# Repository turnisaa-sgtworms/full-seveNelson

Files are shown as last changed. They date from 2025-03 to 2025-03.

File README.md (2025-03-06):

my fun little keeb: 



designed to fit in a 60% case (minus two of the mounting points)

7u main cluster with a southy num pad and arrow keys/mini nav cluster

stm32 powered

built with the help of this guide: https://youtu.be/kGKN8SGkUD0?si=LNXGM9T6t6xvs4m5
by noah kiser

plate files are added, but will need updated when i fix the spacing :(

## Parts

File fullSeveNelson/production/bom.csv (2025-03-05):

Designator | Footprint | Quantity | Value | LCSC Part #
 |  | 1
BOOT1, RST1 | SW_SPST_TL3342 | 2 | SW_SPST
C1, C3, C4, C5, C6, C7, C8 | 0402 | 7 | 100nF | C307331
C10, C9 | 0402 | 2 | 1uF | C307331
C2 | 0603 | 1 | 10uF | C307331
D10, D11, D12, D13, D14, D15, D16, D17, D18, D19, D2, D20, D21, D22, D23, D24, D25, D26, D27, D28, D29, D3, D30, D31, D32, D33, D34, D35, D36, D37, D38, D39, D4, D40, D41, D42, D43, D44, D45, D46, D47, D48, D49, D5, D50, D51, D52, D53, D54, D55, D56, D57, D58, D6, D7, D8, D9 | D_SOD-123 | 57 | D_Small
F1 | 1206 | 1 | 500mA | C135341
J1 | USB_C_Receptacle_HRO_TYPE-C-31-M-12 | 1 | USB_C_Receptacle_USB2.0
MX10, MX11, MX12, MX13, MX14, MX15, MX16, MX17, MX18, MX19, MX2, MX20, MX21, MX22, MX23, MX24, MX25, MX26, MX27, MX28, MX29, MX3, MX30, MX31, MX32, MX33, MX34, MX35, MX36, MX37, MX38, MX39, MX4, MX40, MX41, MX42, MX43, MX44, MX45, MX46, MX47, MX48, MX49, MX5, MX50, MX51, MX52, MX53, MX54, MX55, MX56, MX57, MX58, MX6, MX7, MX8, MX9 | SW_MX_HS_CPG151101S11_1u | 57 | MX_SW_HS
R1, R2, R3, R4 | 0402 | 4 | 5.1k
U1 | LQFP-48_7x7mm_P0.5mm | 1 | STM32F072CBT6
U2 | SOT-143 | 1 | PRTR5V0U2X | C2827688
U3 | SOT-23 | 1 | XC6206PxxxMR-Regulator_Linear | C5446

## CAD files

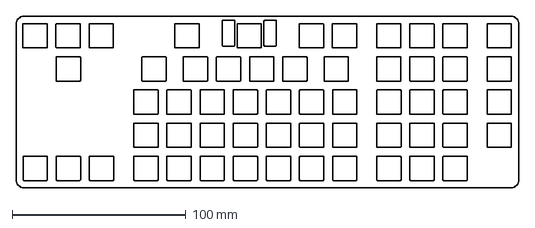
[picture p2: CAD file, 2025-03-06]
plate files/fsnPlate.dxf
289.0 x 98.6 mm

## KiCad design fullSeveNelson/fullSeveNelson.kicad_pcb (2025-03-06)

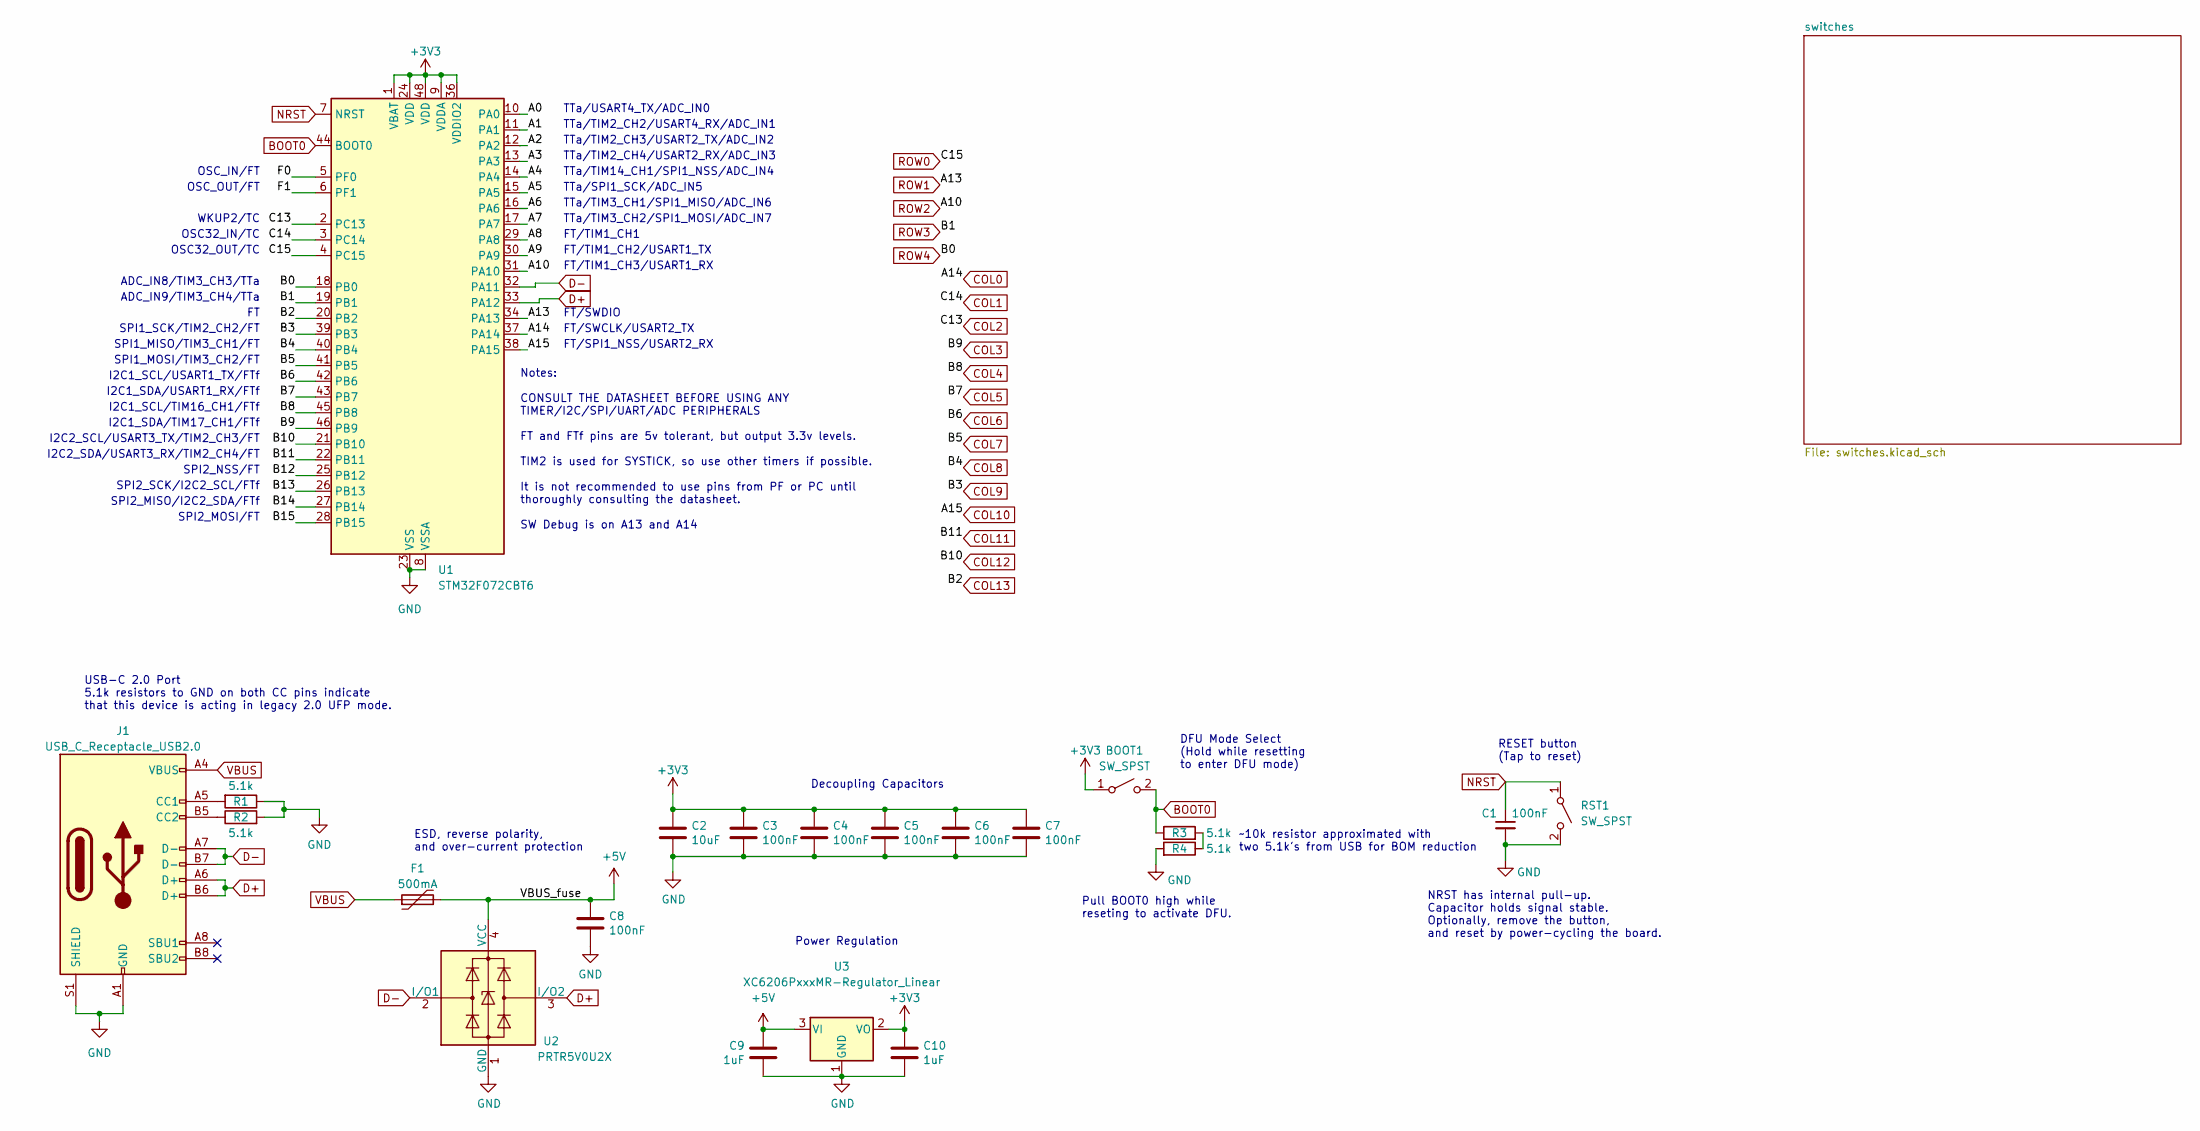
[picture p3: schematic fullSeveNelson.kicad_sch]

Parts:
BOOT1: SW_SPST; SW_SPST_TL3342
C1, C3, C4, C5, C6, C7, C8: 100nF; C_0402_1005Metric; LCSC C307331
C2: 10uF; C_0603_1608Metric; LCSC C307331
C9, C10: 1uF; C_0402_1005Metric; LCSC C307331
F1: 500mA; Fuse_1206_3216Metric; LCSC C135341
J1: USB_C_Receptacle_USB2.0; USB_C_Receptacle_HRO_TYPE-C-31-M-12; JlcRotOffset 180
R1, R2, R3, R4: 5.1k; R_0402_1005Metric
RST1: SW_SPST; SW_SPST_TL3342
U1: STM32F072CBT6; LQFP-48_7x7mm_P0.5mm; JlcRotOffset 90
U2: PRTR5V0U2X; SOT-143; LCSC C2827688
U3: XC6206PxxxMR-Regulator_Linear; SOT-23; LCSC C5446

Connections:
+3V3: BOOT1.1 (A), C2.1, C3.1, C4.1, C5.1, C6.1, C7.1, C10.1, U1.1 (VBAT), U1.9 (VDDA), U1.24 (VDD), U1.36 (VDDIO2), U1.48 (VDD), U3.2 (VO)
+5V: C8.1, C9.1, F1.2, U2.4 (VCC), U3.3 (VI)
/A0: U1.10 (PA0)
/A1: U1.11 (PA1)
/A2: U1.12 (PA2)
/A3: U1.13 (PA3)
/A4: U1.14 (PA4)
/A5: U1.15 (PA5)
/A6: U1.16 (PA6)
/A7: U1.17 (PA7)
/A8: U1.29 (PA8)
/A9: U1.30 (PA9)
/B12: U1.25 (PB12)
/B13: U1.26 (PB13)
/B14: U1.27 (PB14)
/B15: U1.28 (PB15)
/F0: U1.5 (PF0)
/F1: U1.6 (PF1)
BOOT0: BOOT1.2 (B), R3.1, U1.44 (BOOT0)
COL0: U1.37 (PA14); also elsewhere on the board
COL1: U1.3 (PC14); also elsewhere on the board
COL2: U1.2 (PC13); also elsewhere on the board
COL3: U1.46 (PB9); also elsewhere on the board
COL4: U1.45 (PB8); also elsewhere on the board
COL5: U1.43 (PB7); also elsewhere on the board
COL6: U1.42 (PB6); also elsewhere on the board
COL7: U1.41 (PB5); also elsewhere on the board
COL8: U1.40 (PB4); also elsewhere on the board
COL9: U1.39 (PB3); also elsewhere on the board
COL10: U1.38 (PA15); also elsewhere on the board
COL11: U1.22 (PB11); also elsewhere on the board
COL12: U1.21 (PB10); also elsewhere on the board
COL13: U1.20 (PB2); also elsewhere on the board
D+: J1.A6 (D+), J1.B6 (D+), U1.33 (PA12), U2.3 (I/O2)
D-: J1.A7 (D-), J1.B7 (D-), U1.32 (PA11), U2.2 (I/O1)
GND: C1.2, C2.2, C3.2, C4.2, C5.2, C6.2, C7.2, C8.2, C9.2, C10.2, J1.A1 (GND), J1.A12 (GND), J1.B1 (GND), J1.B12 (GND), J1.S1 (SHIELD), R1.1, R2.2, R4.2, RST1.2 (B), U1.8 (VSSA), U1.23 (VSS), U1.35 (VSS), U1.47 (VSS), U2.1 (GND), U3.1 (GND)
NRST: C1.1, RST1.1 (A), U1.7 (NRST)
unnamed: J1.A5 (CC1), R1.2
unnamed: J1.B5 (CC2), R2.1
unnamed: R3.2, R4.1
ROW0: U1.4 (PC15); also elsewhere on the board
ROW1: U1.34 (PA13); also elsewhere on the board
ROW2: U1.31 (PA10); also elsewhere on the board
ROW3: U1.19 (PB1); also elsewhere on the board
ROW4: U1.18 (PB0); also elsewhere on the board
VBUS: F1.1, J1.A4 (VBUS), J1.A9 (VBUS), J1.B4 (VBUS), J1.B9 (VBUS)

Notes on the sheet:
SPI1_SCK/TIM2_CH2/FT
FT/TIM1_CH1
FT/TIM1_CH3/USART1_RX
SPI2_NSS/FT
Notes: CONSULT THE DATASHEET BEFORE USING ANY TIMER/I2C/SPI/UART/ADC PERIPHERALS FT and FTf pins are 5v tolerant, but output 3.3v levels. TIM2 is used for SYSTICK, so use other timers if possible. It is not recommended to use pins from PF or PC until thoroughly consulting the datasheet. SW Debug is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
TTa/TIM2_CH4/USART2_RX/ADC_IN3
NRST has internal pull-up. Capacitor holds signal stable. Optionally, remove the button, and reset by power-cycling the board.
FT/SWDIO
Decoupling Capacitors
SPI1_MOSI/TIM3_CH2/FT
ADC_IN9/TIM3_CH4/TTa
I2C2_SCL/USART3_TX/TIM2_CH3/FT
SPI2_MISO/I2C2_SDA/FTf
FT/SWCLK/USART2_TX
I2C1_SCL/TIM16_CH1/FTf
~10k resistor approximated with two 5.1k's from USB for BOM reduction
TTa/TIM2_CH2/USART4_RX/ADC_IN1
USB-C 2.0 Port 5.1k resistors to GND on both CC pins indicate that this device is acting in legacy 2.0 UFP mode.
TTa/TIM2_CH3/USART2_TX/ADC_IN2
OSC_IN/FT
DFU Mode Select (Hold while resetting to enter DFU mode)
WKUP2/TC
I2C2_SDA/USART3_RX/TIM2_CH4/FT
ADC_IN8/TIM3_CH3/TTa
RESET button (Tap to reset)
Pull BOOT0 high while reseting to activate DFU.
I2C1_SDA/TIM17_CH1/FTf
TTa/SPI1_SCK/ADC_IN5
TTa/TIM3_CH1/SPI1_MISO/ADC_IN6
TTa/TIM3_CH2/SPI1_MOSI/ADC_IN7
OSC32_OUT/TC
FT/SPI1_NSS/USART2_RX
SPI1_MISO/TIM3_CH1/FT
OSC32_IN/TC
TTa/TIM14_CH1/SPI1_NSS/ADC_IN4
I2C1_SDA/USART1_RX/FTf
SPI2_MOSI/FT
FT/TIM1_CH2/USART1_TX
Power Regulation
SPI2_SCK/I2C2_SCL/FTf

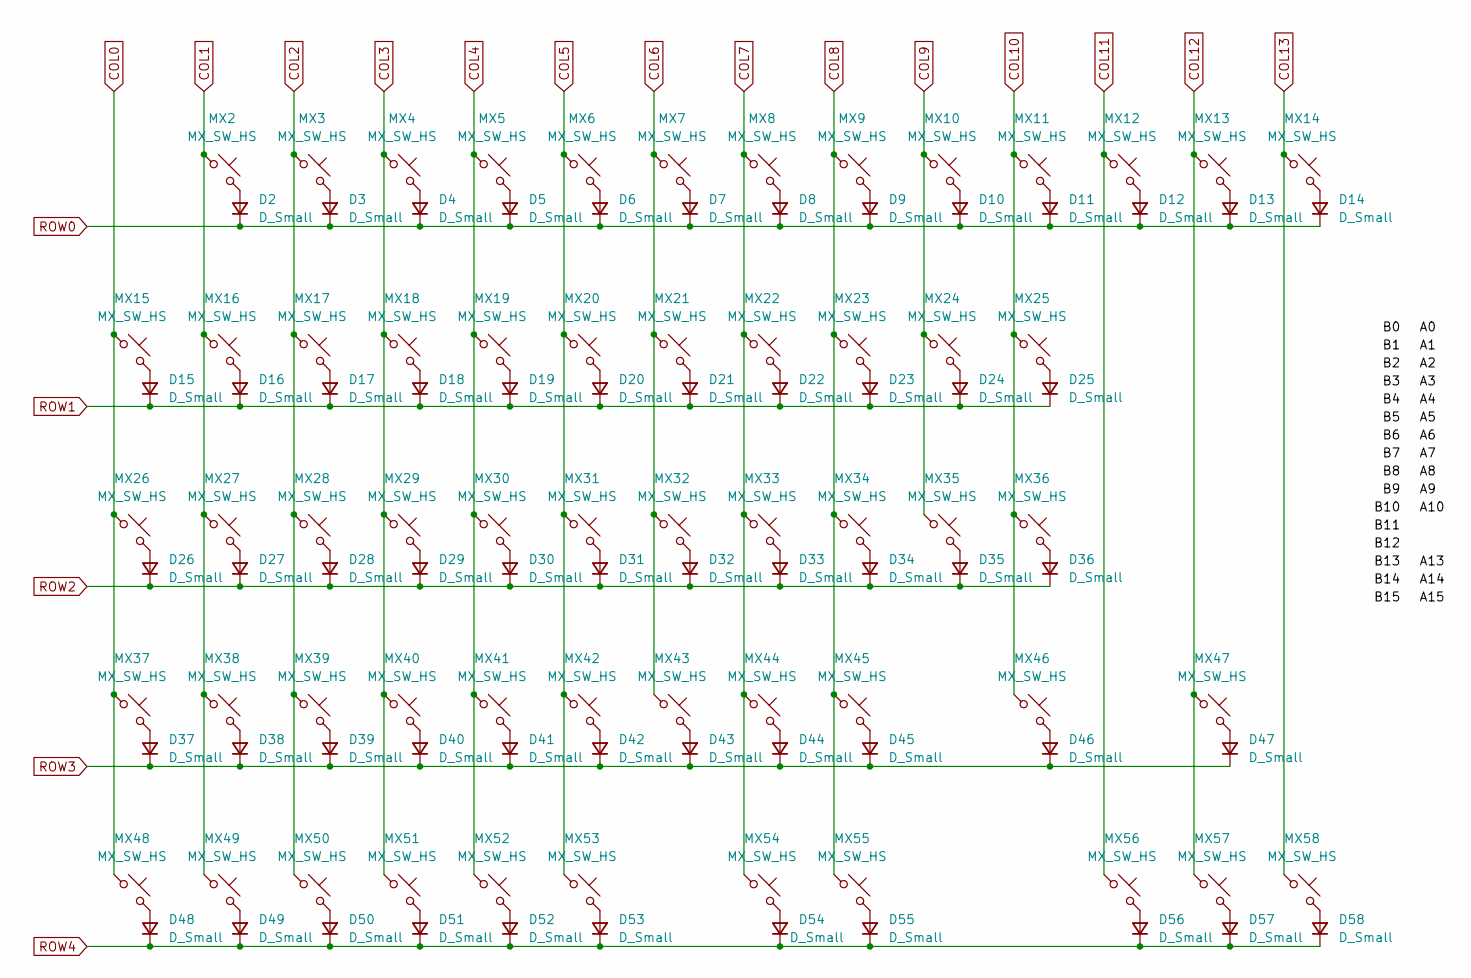
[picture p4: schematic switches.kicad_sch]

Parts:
D2, D3, D4, D5, D6, D7, D8, D9, D10, D11, D12, D13, D14, D15, D16, D17, D18, D19, D20, D21, D22, D23, D24, D25, D26, D27, D28, D29, D30, D31, D32, D33, D34, D35, D36, D37, D38, D39, D40, D41, D42, D43, D44, D45, D46, D47, D48, D49, D50, D51, D52, D53, D54, D55, D56, D57, D58: D_Small; D_SOD-123
MX2, MX3, MX4, MX5, MX6, MX7, MX8, MX9, MX10, MX11, MX12, MX13, MX14, MX15, MX16, MX17, MX18, MX19, MX20, MX21, MX22, MX23, MX24, MX25, MX26, MX27, MX28, MX29, MX30, MX31, MX32, MX33, MX34, MX35, MX36, MX37, MX38, MX39, MX40, MX41, MX42, MX43, MX44, MX45, MX46, MX47, MX48, MX49, MX50, MX51, MX52, MX53, MX54, MX55, MX56, MX57, MX58: MX_SW_HS; SW_MX_HS_CPG151101S11_1u

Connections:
COL0: MX15.1, MX26.1, MX37.1, MX48.1; also elsewhere on the board
COL1: MX2.1, MX16.1, MX27.1, MX38.1, MX49.1; also elsewhere on the board
COL2: MX3.1, MX17.1, MX28.1, MX39.1, MX50.1; also elsewhere on the board
COL3: MX4.1, MX18.1, MX29.1, MX40.1, MX51.1; also elsewhere on the board
COL4: MX5.1, MX19.1, MX30.1, MX41.1, MX52.1; also elsewhere on the board
COL5: MX6.1, MX20.1, MX31.1, MX42.1, MX53.1; also elsewhere on the board
COL6: MX7.1, MX21.1, MX32.1, MX43.1; also elsewhere on the board
COL7: MX8.1, MX22.1, MX33.1, MX44.1, MX54.1; also elsewhere on the board
COL8: MX9.1, MX23.1, MX34.1, MX45.1, MX55.1; also elsewhere on the board
COL9: MX10.1, MX24.1, MX35.1; also elsewhere on the board
COL10: MX11.1, MX25.1, MX36.1, MX46.1; also elsewhere on the board
COL11: MX12.1, MX56.1; also elsewhere on the board
COL12: MX13.1, MX47.1, MX57.1; also elsewhere on the board
COL13: MX14.1, MX58.1; also elsewhere on the board
unnamed: D2.2 (A), MX2.2
unnamed: D3.2 (A), MX3.2
unnamed: D4.2 (A), MX4.2
unnamed: D5.2 (A), MX5.2
unnamed: D6.2 (A), MX6.2
unnamed: D7.2 (A), MX7.2
unnamed: D8.2 (A), MX8.2
unnamed: D9.2 (A), MX9.2
unnamed: D10.2 (A), MX10.2
unnamed: D11.2 (A), MX11.2
unnamed: D12.2 (A), MX12.2
unnamed: D13.2 (A), MX13.2
unnamed: D14.2 (A), MX14.2
unnamed: D15.2 (A), MX15.2
unnamed: D16.2 (A), MX16.2
unnamed: D17.2 (A), MX17.2
unnamed: D18.2 (A), MX18.2
unnamed: D19.2 (A), MX19.2
unnamed: D20.2 (A), MX20.2
unnamed: D21.2 (A), MX21.2
unnamed: D22.2 (A), MX22.2
unnamed: D23.2 (A), MX23.2
unnamed: D24.2 (A), MX24.2
unnamed: D25.2 (A), MX25.2
unnamed: D26.2 (A), MX26.2
unnamed: D27.2 (A), MX27.2
unnamed: D28.2 (A), MX28.2
unnamed: D29.2 (A), MX29.2
unnamed: D30.2 (A), MX30.2
unnamed: D31.2 (A), MX31.2
unnamed: D32.2 (A), MX32.2
unnamed: D33.2 (A), MX33.2
unnamed: D34.2 (A), MX34.2
unnamed: D35.2 (A), MX35.2
unnamed: D36.2 (A), MX36.2
unnamed: D37.2 (A), MX37.2
unnamed: D38.2 (A), MX38.2
unnamed: D39.2 (A), MX39.2
unnamed: D40.2 (A), MX40.2
unnamed: D41.2 (A), MX41.2
unnamed: D42.2 (A), MX42.2
unnamed: D43.2 (A), MX43.2
unnamed: D44.2 (A), MX44.2
unnamed: D45.2 (A), MX45.2
unnamed: D46.2 (A), MX46.2
unnamed: D47.2 (A), MX47.2
unnamed: D48.2 (A), MX48.2
unnamed: D49.2 (A), MX49.2
unnamed: D50.2 (A), MX50.2
unnamed: D51.2 (A), MX51.2
unnamed: D52.2 (A), MX52.2
unnamed: D53.2 (A), MX53.2
unnamed: D54.2 (A), MX54.2
unnamed: D55.2 (A), MX55.2
unnamed: D56.2 (A), MX56.2
unnamed: D57.2 (A), MX57.2
unnamed: D58.2 (A), MX58.2
ROW0: D2.1 (K), D3.1 (K), D4.1 (K), D5.1 (K), D6.1 (K), D7.1 (K), D8.1 (K), D9.1 (K), D10.1 (K), D11.1 (K), D12.1 (K), D13.1 (K), D14.1 (K); also elsewhere on the board
ROW1: D15.1 (K), D16.1 (K), D17.1 (K), D18.1 (K), D19.1 (K), D20.1 (K), D21.1 (K), D22.1 (K), D23.1 (K), D24.1 (K), D25.1 (K); also elsewhere on the board
ROW2: D26.1 (K), D27.1 (K), D28.1 (K), D29.1 (K), D30.1 (K), D31.1 (K), D32.1 (K), D33.1 (K), D34.1 (K), D35.1 (K), D36.1 (K); also elsewhere on the board
ROW3: D37.1 (K), D38.1 (K), D39.1 (K), D40.1 (K), D41.1 (K), D42.1 (K), D43.1 (K), D44.1 (K), D45.1 (K), D46.1 (K), D47.1 (K); also elsewhere on the board
ROW4: D48.1 (K), D49.1 (K), D50.1 (K), D51.1 (K), D52.1 (K), D53.1 (K), D54.1 (K), D55.1 (K), D56.1 (K), D57.1 (K), D58.1 (K); also elsewhere on the board

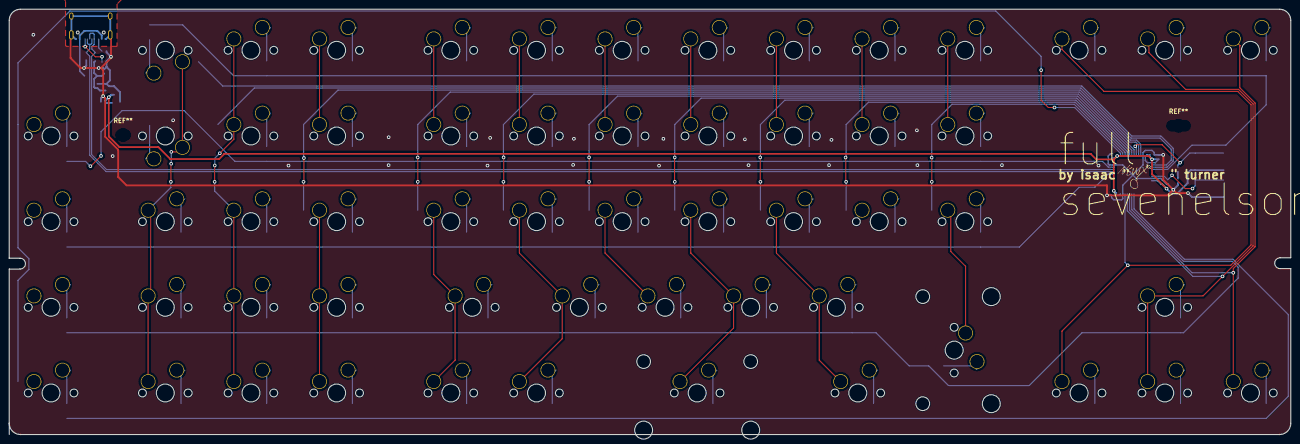
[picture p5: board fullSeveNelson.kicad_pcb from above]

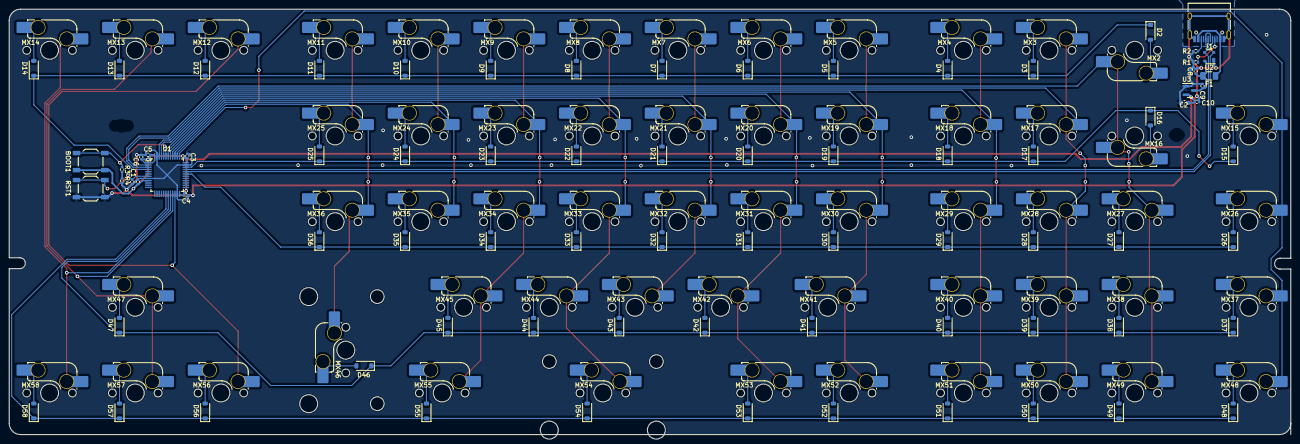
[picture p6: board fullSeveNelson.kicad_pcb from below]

Board: 2 copper layers, 285.0 x 94.6 mm, 135 parts (135 on the bottom side), 87 nets.

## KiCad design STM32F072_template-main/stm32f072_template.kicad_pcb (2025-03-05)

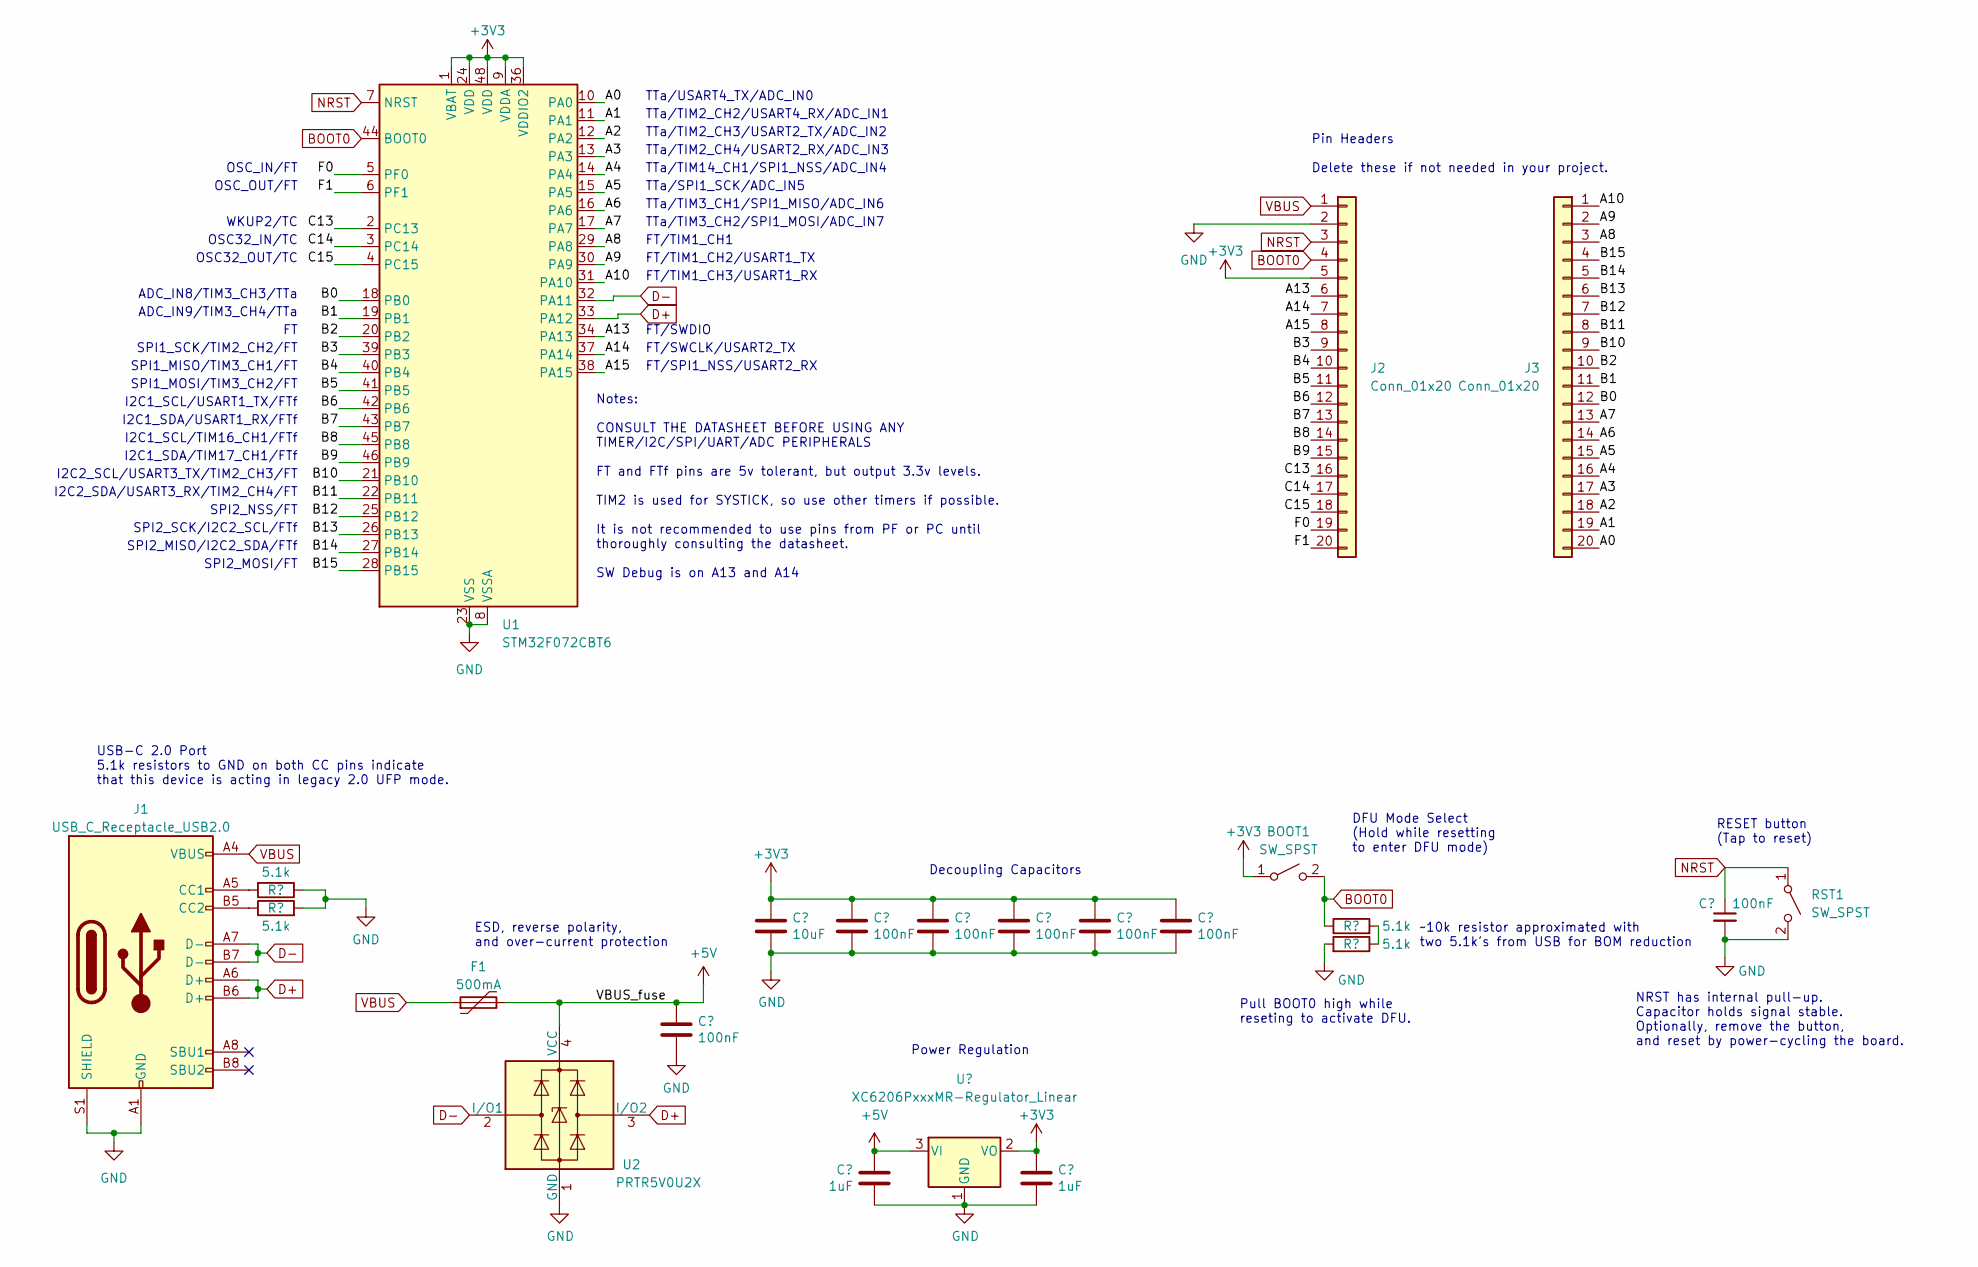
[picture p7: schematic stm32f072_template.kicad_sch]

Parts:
BOOT1: SW_SPST; SW_SPST_TL3342
C1, C3, C4, C5, C6, C7, C8: 100nF; C_0402_1005Metric; LCSC C307331
C2: 10uF; C_0603_1608Metric; LCSC C307331
C9, C10: 1uF; C_0402_1005Metric; LCSC C307331
F1: 500mA; Fuse_1206_3216Metric; LCSC C135341
J1: USB_C_Receptacle_USB2.0; USB_C_Receptacle_HRO_TYPE-C-31-M-12; JlcRotOffset 180
J2, J3: Conn_01x20; PinHeader_1x20_P2.54mm_Vertical
R1, R2, R3, R4: 5.1k; R_0402_1005Metric
RST1: SW_SPST; SW_SPST_TL3342
U1: STM32F072CBT6; LQFP-48_7x7mm_P0.5mm; JlcRotOffset 90
U2: PRTR5V0U2X; SOT-143; LCSC C2827688
U3: XC6206PxxxMR-Regulator_Linear; SOT-23; LCSC C5446

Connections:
+3V3: BOOT1.1 (A), C2.1, C3.1, C4.1, C5.1, C6.1, C7.1, C10.1, J2.5, U1.1 (VBAT), U1.9 (VDDA), U1.24 (VDD), U1.36 (VDDIO2), U1.48 (VDD), U3.2 (VO)
+5V: C8.1, C9.1, F1.2, U2.4 (VCC), U3.3 (VI)
/A0: J3.20, U1.10 (PA0)
/A1: J3.19, U1.11 (PA1)
/A2: J3.18, U1.12 (PA2)
/A3: J3.17, U1.13 (PA3)
/A4: J3.16, U1.14 (PA4)
/A5: J3.15, U1.15 (PA5)
/A6: J3.14, U1.16 (PA6)
/A7: J3.13, U1.17 (PA7)
/A8: J3.3, U1.29 (PA8)
/A9: J3.2, U1.30 (PA9)
/A10: J3.1, U1.31 (PA10)
/A13: J2.6, U1.34 (PA13)
/A14: J2.7, U1.37 (PA14)
/A15: J2.8, U1.38 (PA15)
/B0: J3.12, U1.18 (PB0)
/B1: J3.11, U1.19 (PB1)
/B2: J3.10, U1.20 (PB2)
/B3: J2.9, U1.39 (PB3)
/B4: J2.10, U1.40 (PB4)
/B5: J2.11, U1.41 (PB5)
/B6: J2.12, U1.42 (PB6)
/B7: J2.13, U1.43 (PB7)
/B8: J2.14, U1.45 (PB8)
/B9: J2.15, U1.46 (PB9)
/B10: J3.9, U1.21 (PB10)
/B11: J3.8, U1.22 (PB11)
/B12: J3.7, U1.25 (PB12)
/B13: J3.6, U1.26 (PB13)
/B14: J3.5, U1.27 (PB14)
/B15: J3.4, U1.28 (PB15)
/C13: J2.16, U1.2 (PC13)
/C14: J2.17, U1.3 (PC14)
/C15: J2.18, U1.4 (PC15)
/F0: J2.19, U1.5 (PF0)
/F1: J2.20, U1.6 (PF1)
BOOT0: BOOT1.2 (B), J2.4, R3.1, U1.44 (BOOT0)
GND: C1.2, C2.2, C3.2, C4.2, C5.2, C6.2, C7.2, C8.2, C9.2, C10.2, J1.A1 (GND), J1.A12 (GND), J1.B1 (GND), J1.B12 (GND), J1.S1 (SHIELD), J2.2, R1.1, R2.2, R4.2, RST1.2 (B), U1.8 (VSSA), U1.23 (VSS), U1.35 (VSS), U1.47 (VSS), U2.1 (GND), U3.1 (GND)
NRST: C1.1, J2.3, RST1.1 (A), U1.7 (NRST)
unnamed: J1.A5 (CC1), R1.2
unnamed: J1.B5 (CC2), R2.1
unnamed: R3.2, R4.1
VBUS: F1.1, J1.A4 (VBUS), J1.A9 (VBUS), J1.B4 (VBUS), J1.B9 (VBUS), J2.1

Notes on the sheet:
SPI1_SCK/TIM2_CH2/FT
Pin Headers Delete these if not needed in your project.
FT/TIM1_CH1
FT/TIM1_CH3/USART1_RX
SPI2_NSS/FT
Notes: CONSULT THE DATASHEET BEFORE USING ANY TIMER/I2C/SPI/UART/ADC PERIPHERALS FT and FTf pins are 5v tolerant, but output 3.3v levels. TIM2 is used for SYSTICK, so use other timers if possible. It is not recommended to use pins from PF or PC until thoroughly consulting the datasheet. SW Debug is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
TTa/TIM2_CH4/USART2_RX/ADC_IN3
NRST has internal pull-up. Capacitor holds signal stable. Optionally, remove the button, and reset by power-cycling the board.
FT/SWDIO
Decoupling Capacitors
SPI1_MOSI/TIM3_CH2/FT
ADC_IN9/TIM3_CH4/TTa
I2C2_SCL/USART3_TX/TIM2_CH3/FT
SPI2_MISO/I2C2_SDA/FTf
FT/SWCLK/USART2_TX
I2C1_SCL/TIM16_CH1/FTf
~10k resistor approximated with two 5.1k's from USB for BOM reduction
TTa/TIM2_CH2/USART4_RX/ADC_IN1
USB-C 2.0 Port 5.1k resistors to GND on both CC pins indicate that this device is acting in legacy 2.0 UFP mode.
TTa/TIM2_CH3/USART2_TX/ADC_IN2
OSC_IN/FT
DFU Mode Select (Hold while resetting to enter DFU mode)
WKUP2/TC
I2C2_SDA/USART3_RX/TIM2_CH4/FT
ADC_IN8/TIM3_CH3/TTa
RESET button (Tap to reset)
Pull BOOT0 high while reseting to activate DFU.
I2C1_SDA/TIM17_CH1/FTf
TTa/SPI1_SCK/ADC_IN5
TTa/TIM3_CH1/SPI1_MISO/ADC_IN6
TTa/TIM3_CH2/SPI1_MOSI/ADC_IN7
OSC32_OUT/TC
FT/SPI1_NSS/USART2_RX
SPI1_MISO/TIM3_CH1/FT
OSC32_IN/TC
TTa/TIM14_CH1/SPI1_NSS/ADC_IN4
I2C1_SDA/USART1_RX/FTf
SPI2_MOSI/FT
FT/TIM1_CH2/USART1_TX
Power Regulation

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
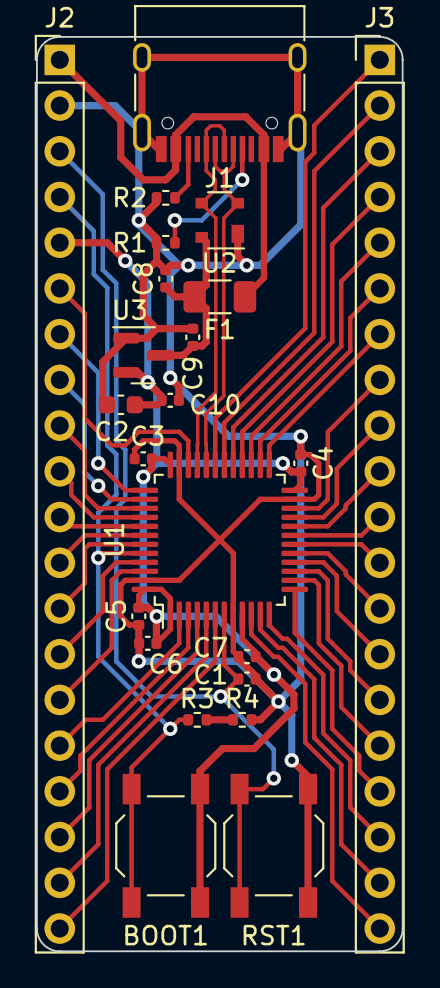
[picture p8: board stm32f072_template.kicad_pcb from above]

Board: 2 copper layers, 20.3 x 50.8 mm, 23 parts (0 on the bottom side), 46 nets.

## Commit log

2025-03-05 created repo 😎
    [stm32f072_template.kicad_pcb, stm32f072_template.kicad_sch]
2025-03-05 made fullSeveNelson
    [bom.csv, designators.csv, fullSeveNelson.kicad_pcb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]
2025-03-05 updated fills
    [fullSeveNelson.kicad_pcb]
2025-03-05 fixed footprints
    [fullSeveNelson.kicad_sch, switches.kicad_sch]
2025-03-05 plate files
    [fsnPCB.step, fsnPlate.dxf, fsnPlate.step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]
2025-03-06 fixed spacing and mounting holes
    [fullSeveNelson.kicad_pcb]
2025-03-06 fixed plate for new spacing
    [fsnPCB.step, fsnPlate.dxf, fsnPlate.step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]
